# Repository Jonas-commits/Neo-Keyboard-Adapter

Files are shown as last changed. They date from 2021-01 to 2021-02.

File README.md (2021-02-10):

# Neo Layout Hardware Adapter
This project implements a hardware driver for the [Neo-Layout](https://neo-layout.org/). It works by using an Arduino Mirco. The Arduino registers as BootKeyboard Human Interface Device to the Host using the [HID-Project Library](https://github.com/NicoHood/HID) on the one side. On the other side, we attach a USB Host Shield to the Arduino to make it act as a USB Host for a BootKeyboard itself, using the BootKeyboard Library from the [USB Host Shield Project](https://github.com/felis/USB_Host_Shield_2.0/). Then we run the inputs through a transformation Matrix to map it to the according to Input on the normal German Keyboard layout.

Why all this? For Linux, the Linux build-in Layout works well what I can tell from my experience, but for Windows, there are countless issues with both the software drives. One reason being additional modifiers added and lock Keys (Num-lock, CAPS-Lock) having a non-standard implementation. That confuses windows, so we have not always the behavior we want in all apps. Key-Combinations do not work and Remote-Desktop applications and Screen sharing behave differently every time. With this hardware solution, our layout stays transparent for Windows and when we press Mod3-J, we just send Shift-8 to the host for an open left bracket. No application will ever know we modified our layout. Especially with desktop sharing and VPN connections, that puts a lot of relief in productional use. You can even have two keyboards connected to the PC, where you are using neo-layout and the other person is using the german layout (not sure if this is real use case)

This project can also be modified for other Keyboard-transforming applications, like passing through everything, but playing macro sequences for some key-presses or having any layout you want.

## Setup Project
### Setup Hardware
* Arduino Pro Micro 3.3V (**not 5V**) [Ebay](https://www.ebay.de/itm/Eckstein-Pro-micro-3-3V-8MHz-Arduino-mini-Leonardo-compatible-board-QITA/353159955592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)
* Arduino Micro Host Shield [Ebay](https://www.ebay.de/itm/Mini-USB-Host-Shield-Support-Google-ADK-Android-For-Arduino-UNO-MEGA-Duemilanove/264728254334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)

### Arduino Pro Micro:
* Download Arduino IDE https://www.arduino.cc/en/software
* **Do not** attempt to flash a sketch by selecting the "Arduino Pro Micro" in the List. It will work, but soft-brick the device for further programming.
* Use the Entry "Lily Pad USB" instead. Although this is not a Lily Pad, it shares the relevant specifications

### Mirco USB Host Shield:
* USB runs with 5V, but the board is 3.3V only and therefore has a design flaw and has to be fixed
* Furthermore, the reset pin of the shield (**Not** the reset pin of the Arduino) has to be connected to 3.3V. Unfortunately, this pin is GND in Arduino, so we cannot just set the Pin to HIGH. I went straight after following setup: https://geekhack.org/index.php?topic=80421.0 which i documented also under [here](hardware/Setup.md)

### Software 
* The USB Host Shield Library has to be installed in the Arduino Library Manager
* The HID-Project Library has to be installed in the Arduino Library Manager, standard Keyboard Library is insufficient.
* After uploading the [example](https://github.com/felis/USB_Host_Shield_2.0/blob/master/examples/HID/USBHIDBootKbd/USBHIDBootKbd.ino) to the board I can see the board working in the serial port monitor. 

## Controlling the driver
The Left Windows-Key is configured to interact with the driver. Following (under windows anyhow unused combinations) are therefore used to interact with the driver and are not passed to the Host-PC. To reach this behavior, the left Windows-Key behaves differently in that way. Therefore it does not appear in a pressed-State to the Host before another non-used combination is pressed or the Key is released without pressing a key. In practical use, you will not notice this difference. Please note, that only the left Windows-Key is configured for this use, not the right one. The settings are not stored to EEPROM and therefore reset after each power-reset from the Arduino. This behavior is intended.

### Combinations:
#### Toggle Mapping:

* **WIN + F12**: Toggle between Neo-Mapping and transparent pass-through mode. (Default: Neo-Layout)

#### Toggle Unicode Input:

* **WIN + F1**: Opens the browser with this repository.
* **WIN + F9**: Unicode will be entered in decimal for Windows. (Default)
* **WIN + F10**: Unicode will be entered in hexadecimal for Windows. (Requires setup)
* **WIN + SHIFT + F10**: The registry entry for hexadecimal input in Windows is created. (Requires reboot)
* **WIN + F11**: Unicode will be entered in hexadecimal for Linux.

General note for Unicode on Windows: The decimal method only works in some apps (mainly MS Office) for all Unicode characters. For non-supported apps, only some of the Unicode Keys work. Hexadecimal setup does not require admin rights, but a reboot. It works with most apps, but apparently not with those where the decimal input is fully supported. So you have to toggle the Unicode method in respective to the app you are using. Linux is according to the specification I found, but untested. 

To make life easier, I included a small [ahk-tool](/winUnicodeHelper) which makes the Default method in windows work universally.

#### Media Keys:
Additionally to the Neo Layout, I mapped custom combinations for Media Keys to Layer 4. This is a workaround for the not yet working media keys on the keyboard on the one hand and also spice up standard keyboards.

* **L4 + Page Up**: Volume Up
* **L4 + Page Down**: Volume Down
* **L4 + Insert**: Mute
* **L4 + Delete**: Play/Pause
* **L4 + Home**: Previous Track
* **L4 + End**: Next Track

## Deviations:
As we have full control over the LEDs without changing the actual Locking state reported to the host, I decided to have the NUM-Lock LED switched off in the case of M4-Lock. Furthermore, all LEDs are lit, when the keyboard is in compose-State.

## Limitations:
* No universal Unicode input method which works in all applications and does not require additional software available for Windows.
* As we are using HID-Boot Protocol, only the “normal” keys on your keyboard are supported. Media Keys Readin or whatever else you have on your keyboard is not supported. However, I mapped the most important Media Keys to L4 Layer, and you can map like many other as you want if you edit the source code ☺.
* Because of storage limitations, only compose sequences leading to a 2-Byte Unicode-Character could be considered. The goal is to have a almost complete version as in Neo-Layout. For further storage reasons, letters with diacrical marks can only be accessed by the most common and intuitive way, using the corresponing dead key. You can compile your own compose sequences by adding them in a \*.module file and compile it to C++-Code with the included [Python-Script](src/compose_generator/generate.py)



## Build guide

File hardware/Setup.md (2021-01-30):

# Setup Hardware
## Step 1
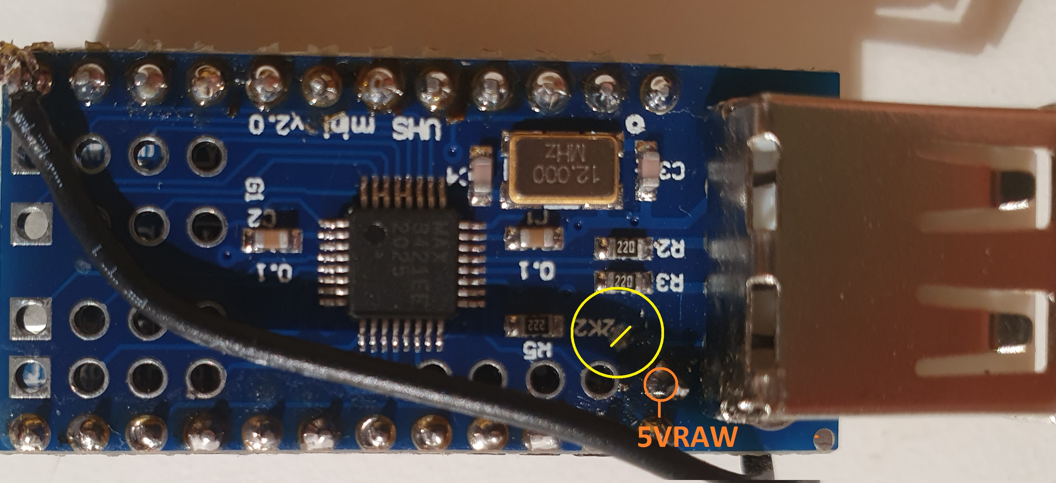
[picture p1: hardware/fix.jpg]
view1

- 1: Take the Mirco UBS Host shield and cut the VBus Wire at the Spot marked in yellow. 
- 2: Solder a new wire to the pin marked in orange. This will be soldered directly to the RAW Pin of the Arduino Mirco

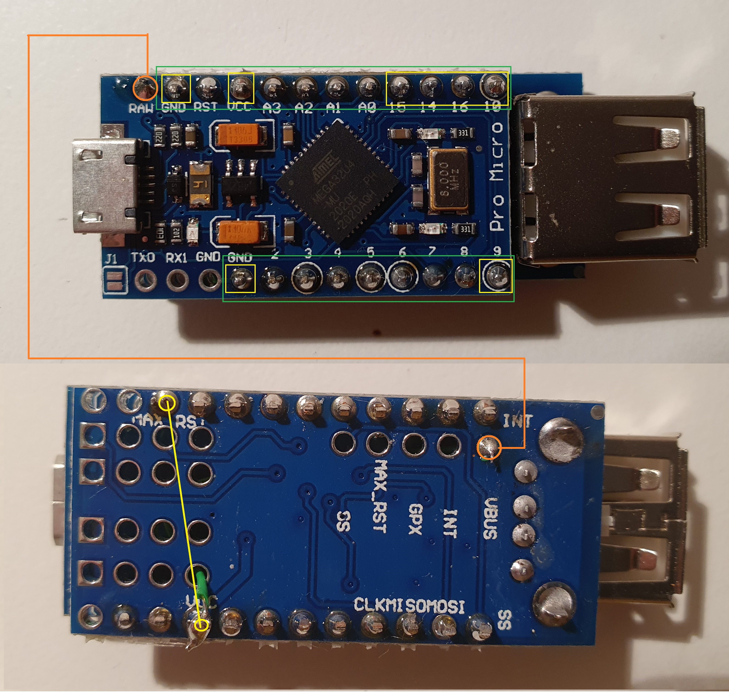
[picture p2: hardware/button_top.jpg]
view2

- 3: Solder a wire to the reset pin of the host shield. (yellow circle 3rd from the left).
- 4: solder the pin headers to the Arduino. The yellow marked spots are the pins that have to be connected mandatorily. For convenience, I recommend cutting the pin headers to the length marked in green, as interconnecting the other pins does not hurt and is much faster
- 5: Before soldering the pin headers, solder the new VBus power line added in (2) directly to the RAW port of the Arduino. Leave just enough space, that you can connect the Arduino top to top as seen in the picture.
- 6: Place the host shield onto the pin headers from the Arduino micro.
- 7: solder the added reset cable from (3) to the VCC pin along with the pin from the Pin header. (yellow circle 4th from the left).
- 8: Solder the remaining pins.

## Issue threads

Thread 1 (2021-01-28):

Compatibility with other Arduino boards?

tjanson, 2021-01-28:
First off, thank you very much for your work! I really appreciate anyone that lessens the pain of using an obscure keyboard layout on Windows machines. ;)

I’m wondering whether there’s a technical reason you chose the Pro Micro, or whether that’s simply what you happened to have available. Would it be a bad idea to use e.g. an Uno (with compatible shield of course) instead?

Also, am I understanding the "Limitations" section correctly in that all layers (or layers 1–4) are already supported? Because that would be amazing!

Jonas-commits, 2021-01-30:
Hello,
The Arduino Pro Micro was used because of the following reasons:
    • USB Device Capability (can emulate an HID device)
    • USB Host capability with supported hardware
    • Pinning (The Micro Host Shield is almost pin-compatible)
    • Size
    • Pricing (Arduino Pro Micro is around €4, the Micro Host shield is about €4, so total pricing for the setup is around €10)

An Arduino Uno does not have the ability to emulate an HID device and runs on 5V, therefore it cannot be used without additional hardware. Furthermore, it is bulky and expensive, so only disadvantages.
A valid alternative would be a Teensy, however, this drives up cost and is not pin-compatible at all to the USB Host Shield and therefore requires rewiring effort.

After a lot of optimization, the limitations which come from the hardware itself are neglilble. Everything works now (Layers 1-6, Pseudo Layer, and almost all compose sequences). The only problem is Unicode input under windows, which is very little supported by windows, the only way around this is to solve this in software again :)

tjanson, 2021-01-30:
Makes sense. That’s great to hear.

Closed 2021-01-30.

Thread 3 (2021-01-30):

Doku Detailfragen

manuel-91, 2021-01-30:
Hey Jonas,

vielen Dank für das Repo und die ausführliche Dokumentation. Da hast du echt viel Mühe reingesteckt. Ich habe die Hardware erfolgreich aufgebaut (danke für die Bilder mit Markierungen!). Dabei kamen mir ein paar Fragen auf:
1. Was hat es mit dem '[fix](https://github.com/Jonas-commits/Neo-Keyboard-Adapter/blob/master/hardware/fix.jpg)' auf sich?
2. Was mache ich mit der [boards.txt](https://github.com/Jonas-commits/Neo-Keyboard-Adapter/blob/master/hardware/boards.txt)? Ich habe sie nicht gebraucht. Ist die für AVR-dude?
3. Bei mir geht das Uploaden nur wenn ich vorher den Reset auf GND hole und glück beim Timing habe (das Board hat ja leider keinen Reset Button). Ist das nur bei mir so? Falls nicht, würde ich gerne noch eine Zeile in der README.md ergänzen evtl mit Verweis auf [die Fehlermeldung](https://stackoverflow.com/questions/49283074/arduino-leonardo-avrdude-butterfly-recv-programmer-is-not-responding).

...ich bin mal so frei und schreibe die Anfrage auf deutsch, da vermutlich alle Neo User Deutsch sprechen...

Diesen Text habe ich mit deiner Firmware in Neo geschrieben! :-D, Grüße!

Jonas-commits, 2021-01-31:
Hallo:
1. Das Bild zeigt, wo das VBus Wire durchzuschneiden ist und durch einen 5V Anschluss zu ersetzen ist.
2. Ich habe zunächst die board.txt bearbeitet um den 3.3V Arduino Micro zu programmieren, bis ich dann entdeckt habe dass das man auch das Lillypad auswählen kann.
3. ich vermute du hast genau das gemacht, was ich auch zuerst gemacht habe und den Arduino Micro ausgewählt und hast damit den falschen Bootloader auf dem Device (Siehe https://github.com/Jonas-commits/Neo-Keyboard-Adapter#arduino-pro-micro)

manuel-91, 2021-01-31:
1. Ahhh! Ok, jetzt check ichs, das schwarze Kabel ist das orange skizzierte. Ich hatte das Kabel direkt geführt ohne Stiftleiste. Aber den RAW Pin vom Host board habe ich nicht verbunden, funktioniert aber komischerweise trotzdem. Der ist auf 0V... wenn ich es richtig verstanden verbindet das schwarze Kabel + Stift die drei orangenen Kreise:

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

Werde ich nachfädeln.

2. Ah, danke für den Hintergrund.
3. Da bin ich mir eigentlich ziemlich sicher, dass ich das nicht gemacht habe... _"Soft-Brick"_ ohne zu wissen wie an das wieder los wird fand ich ziemlich abschreckend:-P Aber wenn es der falsche Bootloader ist erklärt das, warum die IDE keinen Reset auslösen kann... kriege ich das mit Arduino IDE -> Werkzeuge -> Bootloader brennen wieder hin? Oder bin ich jetzt darauf verdammt bei jedem Flashen den Reset zu drücken? o.O

Jonas-commits, 2021-01-31:
ja, das orangene Kabel ist das schwarze. Ich hatte zunächst das Shield oben drauf gesetzt und 1:1 gepinnt und mich gewundert warum es nicht geht und dann nachgeflickt. das Host Shield braucht die 5V nur an VBus. Es ist nicht erforderlich, die eingemalte Linie nachzuziehen, der Pin ist auf dem Shield nicht verbunden.

Wenn du kein 5V Update machst und es original lässt, kommen halt nur 3V an deiner Tastatur an. Kann reichen, kann auch nicht reichen, nach USB Standard sollte es halt 5V sein, und spätestens wenn du eine beleuchtete Tastatur hast, reicht es nicht mehr.

Der richtige Bootloader wird jedes mal korrigiert beim flashen (deswegen bekommst du überhaupt den falschen drauf), also wenn du das richtige Device auswählst sollte es korrigiert sein.

Ich habe 10 Dinger aus 3 verschiedenen Batches zusammengebaut und kann die Probleme nicht nachvollziehen.

manuel-91, 2021-01-31:
Okay, jetzt funktionierts mit dem Reset per IDE. Vermutlich hatte ich zwischendrin doch die falsche Arduino Version ausgewählt.

Closed 2021-01-31.

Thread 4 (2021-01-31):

Ebene4: wortweises Springen per Strg funktioniert nicht

manuel-91, 2021-01-31:
Ich nutze sehr gerne die Pfeiltasten der 4. Ebene. Diese für sich funktionieren sehr gut, jedoch funktioniert Strg dazu wie erwartet:

(Tastenbezeichnung im Quertz-Sprech)

Ohne Strg:
* AltGr + F = Pfeil rechts :heavy_check_mark:
* AltGr + Umschalt + F = Markieren rechts :heavy_check_mark:

Strg:
* Strg + Echte Pfeiltaste = zum nächsten Wort springen :heavy_check_mark:
* AltGr + Strg + F = zum nächsten Wort springen :no_entry: stattdessen bewegt sich der Cursor nur nach rechts
* AltGr + F (gedrückt halten) + Strg = zum nächsten Wort springen :heavy_check_mark:

Strg + Umschalt:
* Strg + Umschalt + Echte Pfeiltaste = markiere nächstes Wort :heavy_check_mark:
* AltGr + Umschalt + Strg + F= Markiere nächstes Wort :no_entry: stattdessen wird nur das nächste Zeichen markiert
* AltGr + Umschalt + F + Strg = Markiere nächstes Wort :heavy_check_mark:

Pfeil rechts ist hier stellvertredend, für Pfeil links, Pos1/Ende gilt das selbe.

Leider ist der "workaround" zuerst die Pfeiltaste zu erzeugen und dann Strg dazu zu drücken nicht praktikabel, da man dafür die Zeichenwiederholung des Betriebbsystems braucht. Ich habe es hier nur zum Fehler eingrenzen notiert.

Getestet auf Windows und Arch Linux.

Jonas-commits, 2021-01-31:
Klingt plausibel. Nach momentaner Implementierung werden alle Modifier verworfen außerhalb Ebene 1 und 2. Ich werde schauen, was man gegen tun kann

Jonas-commits, 2021-01-31:
Hatte diesen Use-Case nicht bedacht beim Design. Sollte jetzt klappen

manuel-91, 2021-01-31:
Yay! Vielen Dank Jonas für die schnelle Erweiterung, läuft! Ich hatte schon befürchtet, dass das Feature nur durch umfangreicheres Code umgraben ergänzt werden kann, aber du hast ja eine sehr elegante Lösung gefunden :+1:

Closed 2021-01-31.

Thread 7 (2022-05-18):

Pricing

Jonas-commits, 2022-05-18:
When I started the Project the USB host shield was €4+shipping and the Arduino Micro around €7. While the Arduino Micro just grew as expected within the current taxes-lockdown-shortage situation, I see the prices for the USB host shield now start around €20 at ebay. If somebody has better sources please post them here.

Jonas-commits, 2023-10-22:
meanwhile, Pricing stabilized, even though not as cheap as it used to be anymore

Closed 2023-10-22.

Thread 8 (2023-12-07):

Adjustments for alternative Neo Layouts  (Bone / Mine / Noted)

jankrahl, 2023-12-07:
Hello and thank you for this project.
I have my parts arriving soon and want to build this for use with Neo Mine.

Do I need to adjust any other files other than [NeoReportParser.cpp](https://github.com/Jonas-commits/Neo-Keyboard-Adapter/blob/master/src/keyboard/NeoReportParser.cpp)?

If all goes well I will of couse make a pull request for the additional layout.

jankrahl, 2023-12-15:
I have finished most of the work.

Only some keys in layer 5 & 6 do not work, but I am not motivated to fix them for now, as I am not using these layers at all.

Layers 1-4 fully work with the Unicode Helper script and good enough without.

I am still refining some openscad code I wrote for a 3D printet case and will create a pull request afterwards.

Closed 2024-02-12.

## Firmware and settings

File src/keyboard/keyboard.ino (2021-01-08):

// #include <usbhub.h>

#include "NeoReportParser.h"

USB     Usb;
//USBHub     Hub(&Usb);
HIDBoot<USB_HID_PROTOCOL_KEYBOARD>    HidKeyboard(&Usb);

NeoReportParser Prs;

void setup()
{
	BootKeyboard.begin();
	Consumer.begin();

	// Flash LED rapidly in case USB Shield could not be initialized
	if (Usb.Init() == -1) {
		while (true) {
			RXLED0;
			delay(100);
			RXLED1;
			delay(100);
		}
	}
	
	//The USB needs some time
	delay(200);

	HidKeyboard.SetReportParser(0, &Prs);
}

void loop()
{
  Usb.Task();
}

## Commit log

2020-12-04 add documentation for set up 3.3V Pro Micro board
2020-12-05 example strapped down working
2020-12-05 strap serial debug output
2020-12-12 clean up code from the straps, have own modifiers
2020-12-12 get rid of more debug code instead give an error visible to end user
    [keyboard.ino]
2020-12-12 add a switch to toggle between 1:1 mapping
2020-12-18 add m4 lock small fixes and improvements
    [keyboard.ino]
2021-01-01 fix LEDs fix M4-Lock
2021-01-02 most of the time, the list length will be one, let's cover that case to save the length element in that case
2021-01-02 more keys, this will take forever…
2021-01-06 add forgoten symbol 'ﬅ'to compsose list start with dead key ipmlementation
2021-01-07 add '↻' compositions
2021-01-08 bugfix: avoid key not releasing in case somebody presses consumer+normal combinations the same time
2021-01-13 print output to target tree structure ref: https://stackoverflow.com/questions/8484943/construct-a-tree-from-list-os-file-paths-python-performance-dependent
2021-01-15 make Arduino IDE understand the file structure
2021-01-15 print origin of the file
2021-02-02 make ESC also escape potential driver errors
